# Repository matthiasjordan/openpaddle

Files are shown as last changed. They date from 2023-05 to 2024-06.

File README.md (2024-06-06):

# OpenPaddle

A Morse paddle project in OpenSCAD.

It goes without saying but this is free software. If you don't have the TRS jack used in this build, you can change the design to accomodate the TRS jack you want to use. If you think the unit is too small, too large, too long, too short: edit it to suit your needs. You want your call sign embossed? Be my guest.

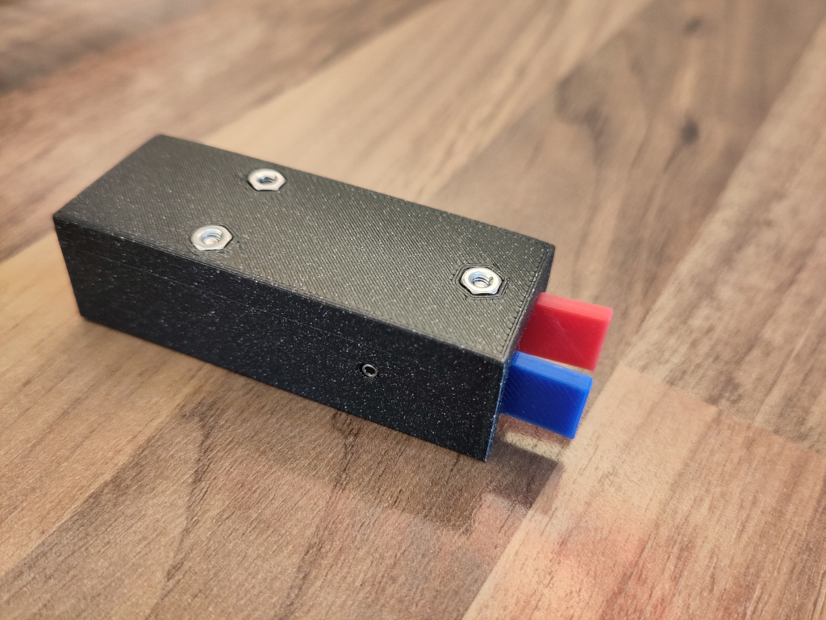
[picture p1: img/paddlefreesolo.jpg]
The bare paddle in a blackish housing


## Bill of materials

There is some [additional hardware needed](BOM.md) to build this project. Some pieces are mandatory to build the paddle but others are optional and can be omitted when certain features are not needed.

## How to build

### Main paddle unit

1. Print the plastic parts
	* [base.scad](base.scad)
		* If you plan (or rather: cannot rule out) to attach the paddle to some sort of base plate later, make sure to pause the print when the base nut fixtures are yet open and insert a 2.5mm nut into each of them. Then resume printing.
	* [case.scad](case.scad)
	* [paddle.scad](paddle.scad)
		* This needs to be printed twice: once straight out of the file and once mirrored.
2. There is a small cylinder fixed at the paddle print. Break it off and attach it with a drop of glue to the paddle right below where it was attached into the round recess. This will later keep the spring in place.
3. Clean the holes for the screws.
4. If paddle adjustment is wanted, put a 2.5mm nut into the slot at the side of the case print. This will keep the grub screw in place. You need to be careful not to push it too far because it will be hard to get out without damaging the print. Then, screw in the grub screws that are used to adjust the paddles.
5. Cut three wired to a length of 2cm, remove about 3mm of insulation from either end. Attach one cable shoe to each of the wires on one end (by crimping or soldering) and solder the other end to the pins of the TRS jack.
6. Using the short screws and a nut, attach the cable shoes that are soldered to the TR pins of the TRS jack to the paddles.
7. Put the TRS jack into the recess at the end of the base print, maybe fixing it using a drop of glue.
8. Put 16mm screws through the holes in the base plate.
9. Slide the paddles on the side screws.
10. Fix the middle contact cable shoe to the middle contact screw using a 2.5mm nut.
11. Slide the case print onto the base assembly, maybe using a bit of force to make it fit. You can use a screw driver to drive the screws into the holes at the top of the case print.
12. Secure the screws at the top using nuts.
13. Use a small TRX screw driver to adjust the paddles with the grub screws.
14. You are QRV.

### Options

* [housing.scad](misc/housing.scad) is a sliding housing ripped off the Palm Pico paddles. Just print it, preferrably standing upwards, secured by some brim.

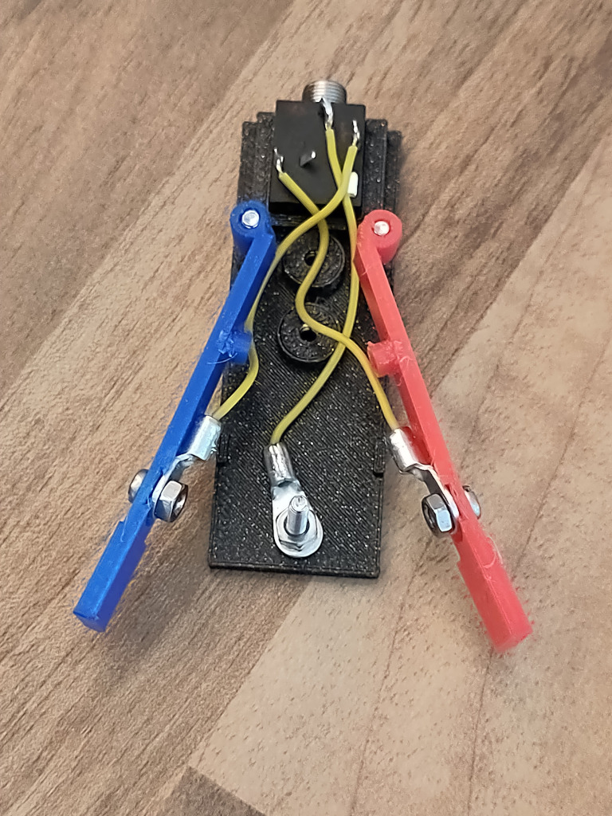
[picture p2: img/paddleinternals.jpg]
The internals


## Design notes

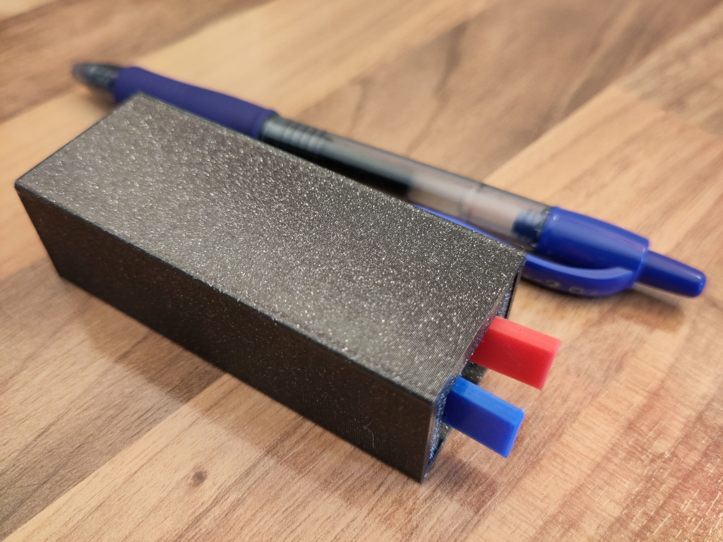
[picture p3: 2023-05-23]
img/housingandpen.jpg

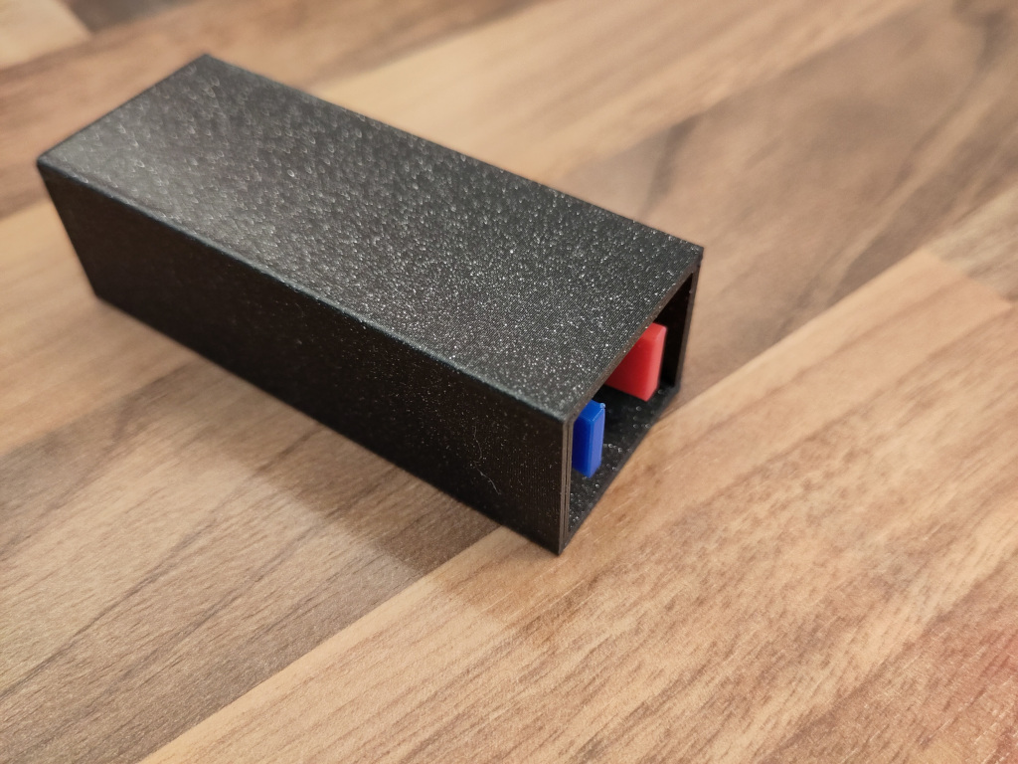
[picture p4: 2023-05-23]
img/paddleinhousing.jpg

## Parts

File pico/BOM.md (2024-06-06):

# Bill of materials for Pico/USB build

## Mandatory

* 1 Raspberry Pi Pico
* 1 pc. spring 0.2mm x 5mm x 12mm
* 3 pcs. screw 2.5mm x 16mm
* 2 pcs. screw 2.5mm x 6mm
* 1 pc. screw 2.5mm x 10mm
* 6 pcs. nut 2.5mm
* 1 pc. 3.5mm jack like this one: https://www.reichelt.de/klinkeneinbaubuchse-3-5-mm-stereo-ebs-35-p7301.html
* 3 pcs. cable shoes hole diam 3.2mm for 1.5mm wire like this one: https://www.reichelt.de/quetschkabelschuh-ringform-lochmass-3-2mm-qs-1-5-3-p24825.html
* 1 pc. wire 1.5mm 5cm
* 1 pc. wire 1.5mm 15cm
* 2 pcs. wire 1.5mm 4.5cm
* 2 pcs. wire 1.5mm 16cm
* 2 drops of glue

## Optional for mounting base plates

* 2 pcs. nut 2.5mm

## Optional for adjusting

* 2 pcs. nut 2.5mm
* 2 pcs. grub screw 2.5mm x 6mm

Driver for grub screws: TX 5 HF

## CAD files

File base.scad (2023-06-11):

/*
    OpenPaddle

    Copyright (C) 2023  Matthias Jordan

    This program is free software: you can redistribute it and/or modify
    it under the terms of the GNU General Public License as published by
    the Free Software Foundation, either version 3 of the License, or
    (at your option) any later version.

    This program is distributed in the hope that it will be useful,
    but WITHOUT ANY WARRANTY; without even the implied warranty of
    MERCHANTABILITY or FITNESS FOR A PARTICULAR PURPOSE.  See the
    GNU General Public License for more details.

    You should have received a copy of the GNU General Public License
    along with this program.  If not, see <https://www.gnu.org/licenses/>.
*/    

//////////////////////////////////////////////////////////////////////
//
//
//  The base, that holds the TRS jack and the paddles
//
//
//////////////////////////////////////////////////////////////////////


include<common.scad>
use<paddle.scad>
use<lib/trsjack_ebs35.scad>




base();

basewidth=width-2*casethickness;
baselength=length-casethickness;



module base() {

    baseplate_all();
    paddle_fixtures();
    middle_contact_fixture();
    trs_jack_fixture();
    
    
    module baseplate_all() {
        difference() {
            baseplate();
            translate([mechstart, border, thickness-0.01]) paddlescrewhole();
            translate([mechstart, basewidth-border, thickness-0.01]) paddlescrewhole();
            translate([mechstart+middlescrewdistance, basewidth/2, thickness-0.01]) paddlescrewhole();
            
            $fn=20;
            for (p = basenutpos) {
                translate([mechstart+p, basewidth/2, -1]) cylinder(d=2.6, h=8);
            }
        }
    }


    module paddle_fixtures() {
        // Fixture for left paddle
        translate([mechstart, border, thickness-0.01]) ringWithScrew(h=rheight);
        // Fixture for right paddle
        translate([mechstart, basewidth-border, thickness-0.01]) ringWithScrew(h=rheight);
    }

    
    module middle_contact_fixture() {
        // Fixture for middle contact
        ring_heightx=0;
        translate([mechstart+middlescrewdistance, basewidth/2, thickness-0.01]) {
            ringWithScrew(h=ring_heightx);

            // Stoppers for cable shoe
            translate([0, 0, 0]) {
                $fn=10;
                cssh=2.5+ring_heightx;
                translate([-10,-3,0]) cylinder(h=cssh, d=2);
                translate([-10,3,0]) cylinder(h=cssh, d=2);
            }

            %translate([0,0,ring_heightx]) {
                %translate([0,0,cableshoeheight]) rotate([180,0,180]) cable_shoe(thickness=cableshoeheight, d1=7.5, d2=paddlescrewdiam);
                %translate([0,0,0.99]) paddle_nut();
            }
        }
    }

    
    module trs_jack_fixture() {
        cutspace=0.08;
        jacklen=14.3;
        jackwidth=11.6;
        jackheight=6.1;
        jackexcentricity=0.5;
        
        difference() {
            jackfixture();

            translate([14.3, -11.6+6+basewidth/2-jackexcentricity, 6.1+thickness]) {
                %translate([cutspace/2, cutspace/2, cutspace/2]) rotate([180,0,180]) trsjack();
                rotate([180,0,180]) minkowski() {
                    trsjack();
                    cube([cutspace,cutspace,cutspace]);
                }
            }
        }
    }


    module baseplate() {
        cube([baselength, basewidth, thickness]);
        translate([length-casethickness-0.01, (basewidth-casehole_width)/2, 0]) cube([casethickness, casehole_width, thickness]);
        
        pluglength=nutdiam-0.5;
        plugwidth=1.5;
        translate([grubscrewpos-(pluglength/2), 0, 0]) cube([pluglength, 1.5, 4]);
        translate([grubscrewpos-(pluglength/2), basewidth-plugwidth, 0]) cube([pluglength, plugwidth, 4]);

        for (p = basenutpos) {
            translate([mechstart+p, basewidth/2, thickness-0.01]) {
                basenut();
            }
        }
    }


    module jackfixture() {
        translate([0, casethickness, 0]) cube([16, basewidth-casethickness*2, thickness*2]);
        translate([-jacksupportdepth+0.01, (basewidth-jacksupportwidth)/2, 0]) cube([jacksupportdepth, jacksupportwidth, thickness*2]);
    }


    module ringWithScrew(h=ring_height) {
        paddle_ring(h+0.01);
        %translate([0,0,basescrewheight-1]) rotate([180, 0, 0]) xscrew(basescrewdiam, basescrewheight);
    }


    module paddlescrewhole() {
        $fn=20;
        translate([0,0,basescrewheight-1]) rotate([180, 0, 0]) screwhole(screwdiam=basescrewdiam+0.5, headconeheight=0, headheight=thickness+5.5, shankheight=basescrewheight, headdiam=basescrewheaddiam+0.5);
    }
    

    module xscrew(d, h) {
        $fn=20;
        screwhole(screwdiam=d, headconeheight=0, headheight=basescrewheadheight, shankheight=h, headdiam=basescrewheaddiam);
    }


    module trsjack() {
        ebs35();
    }
}




module paddles() {
    translate([mechstart, 0, thickness+rheight]) {
        translate([0, basewidth-border, 0]) paddle();
        translate([0, border, 0]) mirror([0,1,0]) paddle();
    }
}

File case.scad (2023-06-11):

/*
    OpenPaddle

    Copyright (C) 2023  Matthias Jordan

    This program is free software: you can redistribute it and/or modify
    it under the terms of the GNU General Public License as published by
    the Free Software Foundation, either version 3 of the License, or
    (at your option) any later version.

    This program is distributed in the hope that it will be useful,
    but WITHOUT ANY WARRANTY; without even the implied warranty of
    MERCHANTABILITY or FITNESS FOR A PARTICULAR PURPOSE.  See the
    GNU General Public License for more details.

    You should have received a copy of the GNU General Public License
    along with this program.  If not, see <https://www.gnu.org/licenses/>.
*/    

//////////////////////////////////////////////////////////////////////
//
//
//  The case, that completes the enclosure
//
//
//////////////////////////////////////////////////////////////////////


include<common.scad>
use<base.scad>
use<lib/trsjack_ebs35.scad>



case();



module case() {
    case_back();
    case_front();
    
    translate([0, 0, 0]) case_side();
    translate([0, width, 0]) mirror([0,1,0]) case_side();
    
    case_top();




    module case_back() {
        $fn=20;
        jackd=6.5;
        translate([-casethickness-0.01, 0.01, 0.005]) {
            difference() {
                cube([casethickness, width, caseheight]);
                translate([-0.1, (width-jacksupportwidth)/2, -0.01]) cube([casethickness+0.2, jacksupportwidth, 6]);
                translate([-0.01, width/2, 6]) rotate([0, 90, 0]) cylinder(h=casethickness+0.02, d=jackd);
            }
        }
    }


    module case_front() {
        hole_width=casehole_width;
        hole_height=14;
        translate([length-casethickness, 0.01, 0.005]) {
            difference() {
                cube([casethickness, width, caseheight]);
                translate([-0.1, (width-hole_width)/2, -0.01]) cube([casethickness+0.2, hole_width, hole_height]);
            }
        }
    }


    module case_side() {
        $fn=15;
        blocksize=nutdiam+2;
        insize=nutdiam+0.5;

        difference() {
            side();
            translate([grubscrewpos-insize/2, casethickness-0.01, 0]) cube([insize, casethickness+0.01, caseheight/2+nutdiam/2]);
            translate([grubscrewpos, 3*casethickness-0.01, caseheight/2]) rotate([90, 0, 0]) cylinder(d=grubscrewdiam+0.2, h=3*casethickness);
        }

        // Grub screw and nut
        % translate([grubscrewpos, 0, caseheight/2]) {
            translate([0, grubscrewlength-0.01, 0]) rotate([90, 0, 0]) cylinder(d=grubscrewdiam-0.2, h=grubscrewlength);
            translate([0, 4, 0]) rotate([90, 0, 0]) paddle_nut();
        }
        
        // caselowerthingie
        translate([5, casethickness-0.01, thickness]) cube([10, caselowerthingiewidth, caselowerthingiewidth]);
        
        module side() {
            translate([-0.1, 0, 0]) cube([length+0.2, casethickness, caseheight]);
            translate([grubscrewpos-(blocksize/2), casethickness-0.001, thickness]) cube([blocksize, 3, caseheight-thickness]);
        }
    }


    module case_top() {
        
        barheight=3.3;
        caseborder=border+casethickness;
        
        module bar(hhh) {
            $fn=15;
            translate([0,0,-hhh+0.01]) cylinder(d=8, h=hhh);
        }
        
        module foo() {
            translate([-casethickness, 0, caseheight-casethickness-0.01]) cube([length+casethickness, width, casethickness]);
            
            translate([mechstart, caseborder, caseheight-nutheight]) bar(barheight);
            translate([mechstart, width-caseborder, caseheight-nutheight]) bar(barheight);
            translate([mechstart+middlescrewdistance, width/2, caseheight-nutheight]) bar(2);
        }
        
        difference() {
            foo();
            translate([mechstart, caseborder, caseheight-nutheight]) paddle_nut_hole();
            translate([mechstart, width-caseborder, caseheight-nutheight]) paddle_nut_hole();
            translate([mechstart+middlescrewdistance, width/2, caseheight-nutheight]) paddle_nut_hole();
        }
    }

}

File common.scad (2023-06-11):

/*
    OpenPaddle

    Copyright (C) 2023  Matthias Jordan

    This program is free software: you can redistribute it and/or modify
    it under the terms of the GNU General Public License as published by
    the Free Software Foundation, either version 3 of the License, or
    (at your option) any later version.

    This program is distributed in the hope that it will be useful,
    but WITHOUT ANY WARRANTY; without even the implied warranty of
    MERCHANTABILITY or FITNESS FOR A PARTICULAR PURPOSE.  See the
    GNU General Public License for more details.

    You should have received a copy of the GNU General Public License
    along with this program.  If not, see <https://www.gnu.org/licenses/>.
*/    

//////////////////////////////////////////////////////////////////////
//
//
//  Common values and code
//
//
//////////////////////////////////////////////////////////////////////


use<BOLTS/BOLTS.scad>
use<lib/cableshoe.scad>
use<lib/screwhole.scad>


width=25;
length=62;
thickness=3;
casethickness=2;
jacksupportdepth=2;
jacksupportwidth=6.5;

basescrewdiam = 2.5;
basescrewheight=16;
basescrewheaddiam=4.2;
basescrewheadheight=1.5;
basenutpos = [0, 10];

caseheight=thickness+basescrewheight;
caselowerthingiewidth=1.8;
casehole_width=17;



paddlelength=52;
paddleheight=7;
paddlethickness=2.0;
paddlescrewdiam=2.5;
paddletiplength=12;
paddletipheight=10;


middlescrewdistance=35;

nutdiam=5;
nutheight=2;
cableshoeheight=1;

grubscrewdiam=2.5;
grubscrewlength=6;
grubscrewpos=middlescrewdistance+10;


mechstart=20;
border=3;



ring_height=0.5;
rheight=ring_height+cableshoeheight+nutheight;


screwholediam = basescrewdiam+0.1;


module paddle_nut() {
    nut1(d1=paddlescrewdiam, s=5, m_max=nutheight);
}

module paddle_nut_hole() {
    nut1(d1=0, s=5, m_max=nutheight+2);
    screwholeheight=4;
    $fn=15;
    translate([0,0,-screwholeheight+0.01]) cylinder(d=basescrewdiam, h=screwholeheight);
}

module basenut() {
    %paddle_nut();
    r=4.1;
    difference() {
        cylinder(r=r, h=2.3);
        paddle_nut_hole();
    }
   translate([0,0,2.29]) cylinder(r=r, h=0.5);    
}

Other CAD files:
fullmodel.scad
common/case.scad
common/common.scad
misc/cleaningtool.scad
misc/housing.scad
paddle.scad
paddle/paddle-common.scad
paddle/paddle-large.scad
paddle/paddle-small.scad
paddle/paddle.scad
pico/base.scad
pico/bottom.scad
pico/fullmodel.scad
pico/paddle.scad
plain/base.scad
plain/fullmodel.scad
plain/paddle.scad

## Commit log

2023-06-11 Made paddle sturdier
    [paddle.scad]
2023-06-11 Lower middle contact with tilt protection
    [base.scad]
2023-06-11 Changes reflecting assembly experience
    [base.scad]
2023-06-11 Removed screw hole head difference
    [base.scad]
2023-06-11 Moved basenut() from base to common
    [base.scad, common.scad]
2023-06-11 Moved casethickness declaration up a few lines
    [common.scad]
2023-06-11 Difference removed from base
    [base.scad]
2023-06-11 Added fullmodel.scad from pico
    [fullmodel.scad]
2023-06-11 Cleanup case.scad
    [case.scad]
2024-06-06 Merged branches
    [base.scad, bottom.scad, case.scad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]
